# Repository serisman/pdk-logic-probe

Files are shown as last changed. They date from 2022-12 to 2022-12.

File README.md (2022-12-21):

# pdk-logic-probe
A simple logic probe, based on the ultra-inexpensive (~$0.03) Padauk microcontrollers.
- LED is Green when Probe pin is LOW.
- LED is Red when Probe pin is HIGH.
- LED is Blue when Probe pin is Floating.

### Links
- [Firmware](firmware/)
- [PCB](pcb/)

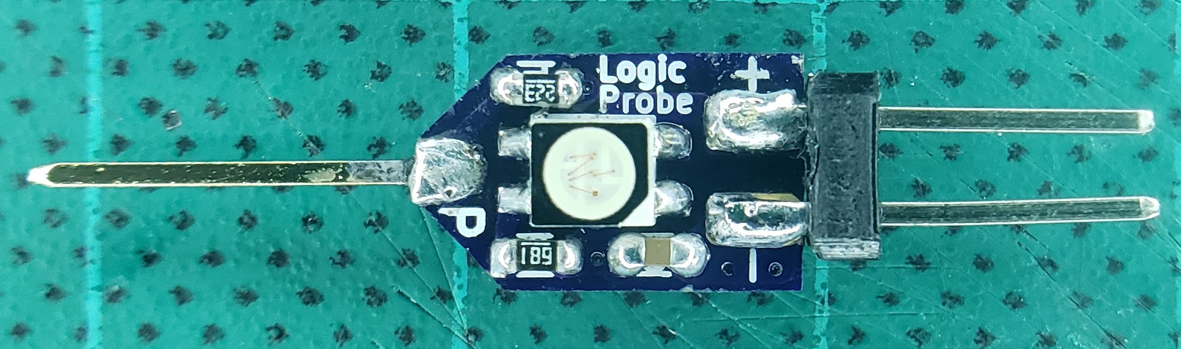
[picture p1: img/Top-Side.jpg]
Top Side

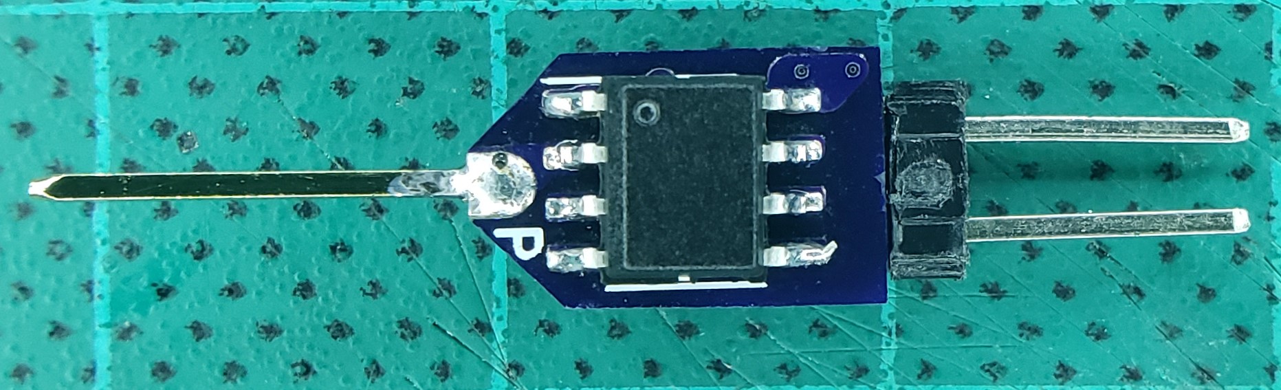
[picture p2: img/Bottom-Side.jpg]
Bottom Side


### Schematic
(for 8-pin PFS154, PFS173, PMS150C/PMS15A, PMS152, PMS154C, PMS171B)
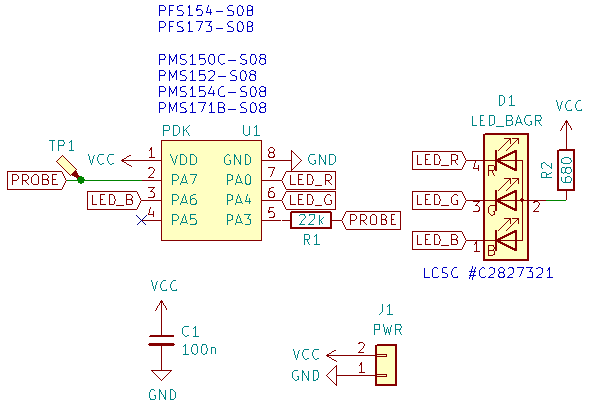
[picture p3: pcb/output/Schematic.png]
Schematic


### Usage
Connect (-) to GND and (+) to VCC
- LED is Green when Probe pin is LOW.
- LED is Red when Probe pin is HIGH.
- LED is Blue when Probe pin is Floating.

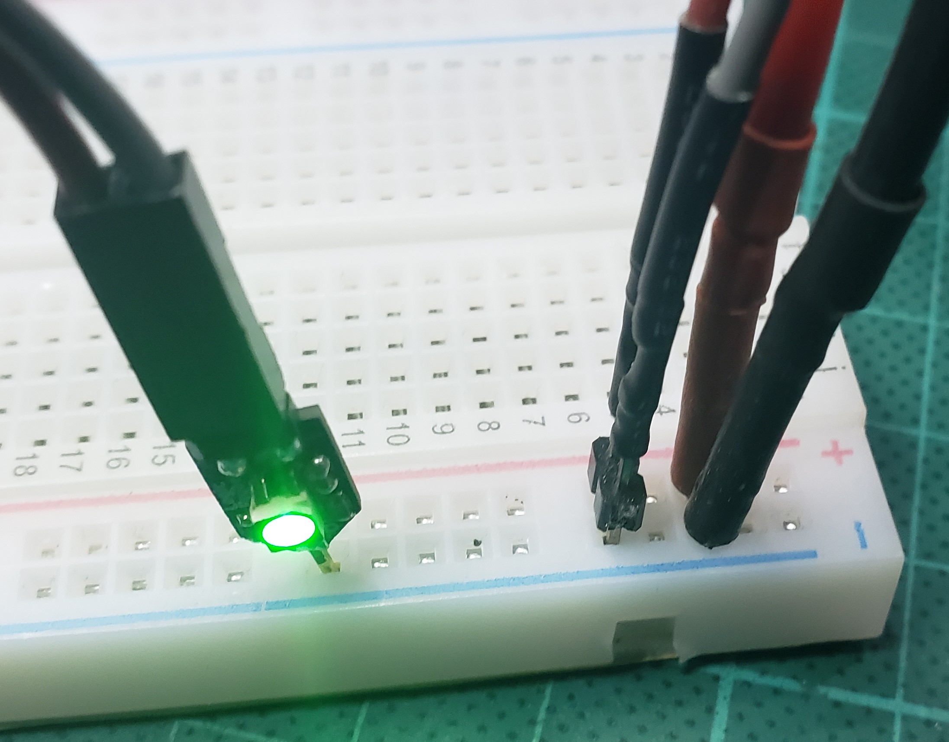
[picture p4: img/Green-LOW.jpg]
Green - LOW

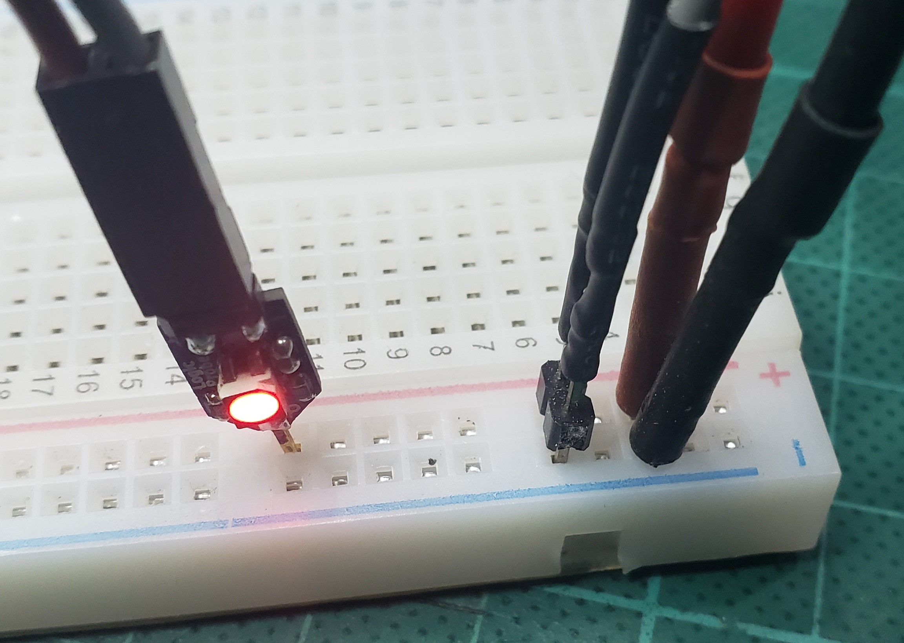
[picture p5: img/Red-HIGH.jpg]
Red - HIGH

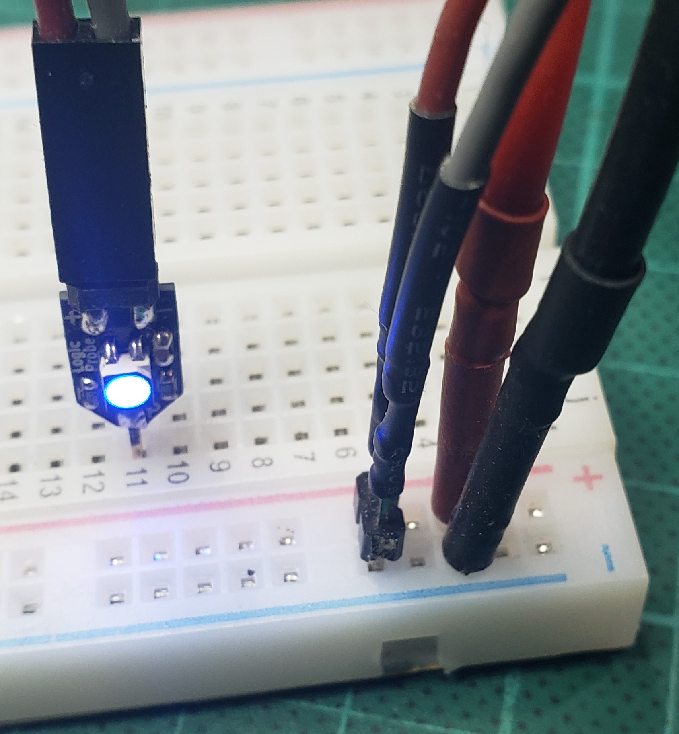
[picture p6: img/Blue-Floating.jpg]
Blue - Floating


### Compatibility
This project is currently intended to be run (without modifications) on the PFS154, PFS173, PMS150C/PMS15A, PMS152, PMS154C, and PMS171B Padauk microcontrollers,
but it should be able to be modified to run on just about every currently known Padauk microcontroller that is supported by SDCC and the Easy PDK Programmer.

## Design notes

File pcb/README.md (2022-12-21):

# pcb ([pdk-logic-probe](https://github.com/serisman/pdk-logic-probe/))

### Schematic
(for 8-pin PFS154, PFS173, PMS150C, PMS15A, PMS152, PMS154C, PMS171B)
Schematic

### PCB

This PCB design was created with KiCad, and has been [shared on OSHPARK](https://oshpark.com/shared_projects/ogOTS65P).
There are also gerber files available in the [output/gerber/](output/gerber/) directory, or [gerber.zip](output/gerber.zip).

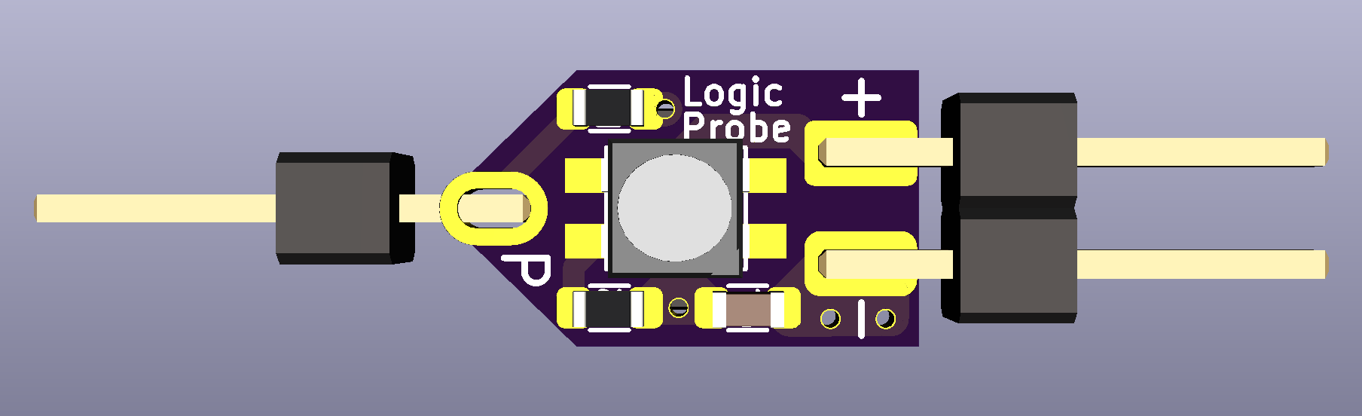
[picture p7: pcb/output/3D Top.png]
3D Top

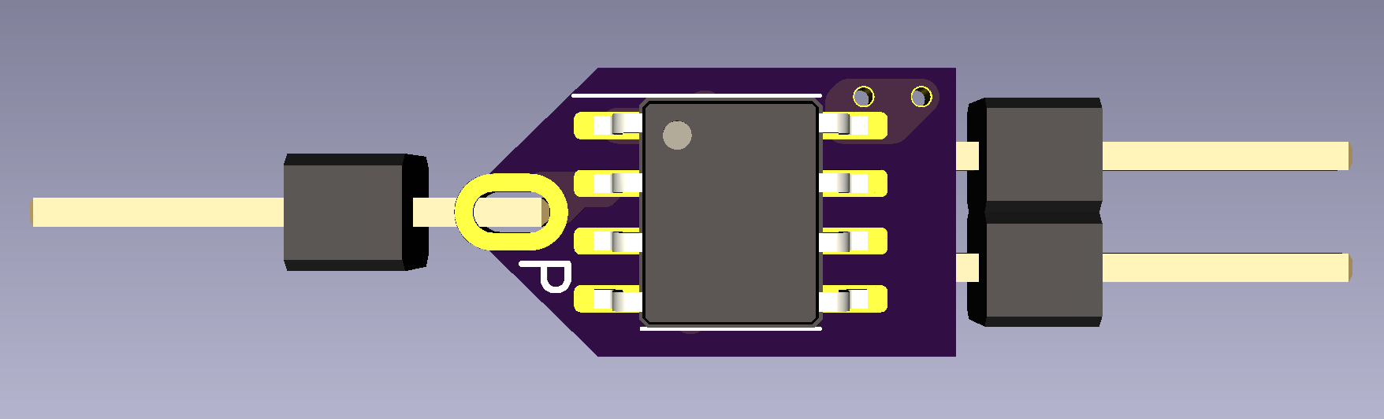
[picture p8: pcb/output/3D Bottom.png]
3D Bottom


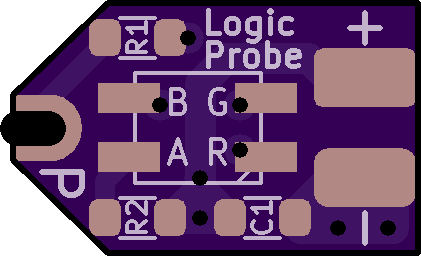
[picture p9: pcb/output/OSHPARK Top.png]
PCB Top

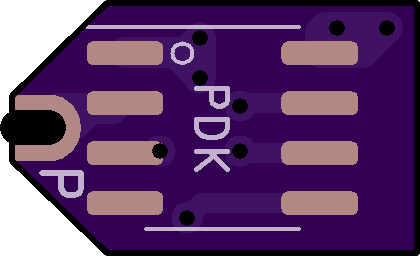
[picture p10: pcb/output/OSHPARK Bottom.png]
PCB Bottom


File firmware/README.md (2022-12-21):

# firmware ([pdk-logic-probe](https://github.com/serisman/pdk-logic-probe/))

### Toolchain:
- The open-source [Small Device C Compiler (SDCC)](http://sdcc.sourceforge.net/)
  - Requires version 3.9.0 or newer - version 4.0.0+ preferred
- The open-source [Easy PDK Programmer](https://github.com/free-pdk/easy-pdk-programmer-software)
  - Requires version 1.3 or newer
- The open-source [pdk-includes](https://github.com/free-pdk/pdk-includes) repository
  - Integrated via local copy into the pdk/ directory
- The open-source [easy-pdk-includes](https://github.com/free-pdk/easy-pdk-includes) repository
  - Integrated via local copy into the easy-pdk/ directory
- Also requires 'make' and other common build tools

### Build Commands:
```
make clean
make build
make size (also calls build)
make program (also calls size which calls build)
```
> Note: These commands can be chained as well.  i.e. `make clean program`

### Customization:
Edit the variables at the top of the Makefile to:
- **DEVICE**: Use a different Padauk MCU (defaults to PFS154)
- **TARGET_VDD_MV**: Use a different voltage while calibrating the internal oscillator (IHRC) (defaults to 3000mV)

> Note: Both of these variables can be changed on the commandline as well.  i.e. `make DEVICE=PFS173 clean program` 

### Compatibility
This project is currently intended to be run (without modifications) on the PFS154, PFS173, PMS150C/PMS15A, PMS152, PMS154C, and PMS171B Padauk microcontrollers,
but it should be able to be modified to run on just about every currently known Padauk microcontroller that is supported by SDCC and the Easy PDK Programmer.
Some microcontrollers will require additional definitions in the [hal.h](hal.h) file,
and less common devices may require additional device specific include files (pdk/device/*.h) to be supplied.

### Build Stats
- Code Size: ~92-97 words (depending on the microcontroller)
- RAM usage: 0 bytes + stack

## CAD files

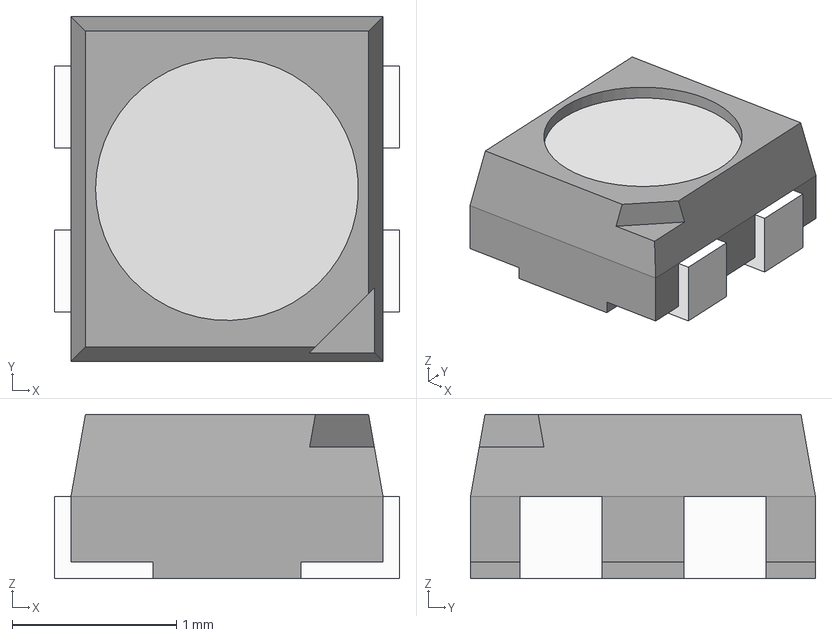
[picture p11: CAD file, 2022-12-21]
pcb/_3dshapes/RGB_LED_2121.step
2.10 x 2.10 x 1.00 mm

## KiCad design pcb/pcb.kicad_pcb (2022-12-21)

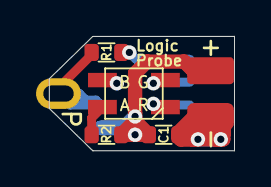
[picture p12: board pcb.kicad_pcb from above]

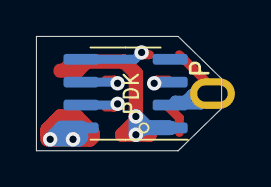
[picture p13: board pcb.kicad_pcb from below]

Board: 2 copper layers, 10.3 x 6.4 mm, 7 parts (2 on the bottom side), 8 nets.

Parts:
C1: 100n; C_0603
D1: LED_BAGR; LED_BAGR_3528
J1: PWR; PinHeader_1x02_P2.54mm_Horizontal
R1: 22k; R_0603
R2: 680; R_0603
TP1: Probe; PinHeader_1x01_P2.54mm_Vertical
U1: PDK; SOIC-8_3.9x4.9mm_P1.27mm

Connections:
GND: C1.2, J1.1, U1.8
LED_B: D1.1, U1.3
LED_G: D1.3, U1.6
LED_R: D1.4, U1.7
unnamed: D1.2, R2.2
unnamed: R1.1, U1.5
PROBE: R1.2, TP1.1, U1.2
VCC: C1.1, J1.2, R2.1, U1.1

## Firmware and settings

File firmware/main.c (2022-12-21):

/*
  pdk-logic-probe

  Copyright (C) 2022  serisman  <github@serisman.com>

  LED is Green when Probe pin is LOW.
  LED is Red when Probe pin is HIGH.
  LED is Blue when Probe pin is Floating.

  ----------------------------------------------------------------------
  CC BY 4.0
  Licensed under a Creative Commons Attribution 4.0 International license:
  http://creativecommons.org/licenses/by/4.0/
*/

#include <stdint.h>
#include <stdbool.h>
#include <pdk/device.h>
#include <easy-pdk/calibrate.h>

#if !defined(PFS154) && !defined(PFS173) && !defined(PMS150C) && !defined(PMS15A) && !defined(PMS152) && !defined(PMS154C) && !defined(PMS171B)
  #error "Device not currently supported!"
#endif

// Note: All pins are on Port A
#define PIN_R       0
#define PIN_G       4
#define PIN_B       6
#define PIN_OUT     3
#define PIN_PROBE   7

// Main program
void main() {

  // Disable wake-up on un-used pins to save power
#if defined(PBDIER)
  PBDIER = 0x00;
#endif
#if defined(PCDIER)
  PCDIER = 0x00;
#endif

  // Initialize Pins
  PAPH = 0x00;                              // Disable pull-up resistors
  PADIER = (uint8_t)(1<<PIN_PROBE);         // Enable digital input on PROBE
  PAC = (uint8_t)((1<<PIN_OUT)|(1<<PIN_R)|(1<<PIN_G)|(1<<PIN_B));  // Set OUT and RGB LED Pins as outputs
  PA = (1<<PIN_R)|(1<<PIN_G)|(1<<PIN_B);    // LEDs off by default

  // Main processing loop
  while (1) {

		PA |= (1<<PIN_OUT);                     // Turn OUT on (i.e. try to pull PROBE high)
		__nop();__nop();__nop();__nop();
		bool probeHigh = PA & (1<<PIN_PROBE);   // Test PROBE

		PA &= ~(1<<PIN_OUT);                    // Turn OUT off (i.e. try to pull PROBE low)
		__nop();__nop();__nop();__nop();
		bool probeLow = !(PA & (1<<PIN_PROBE)); // Test PROBE

		// Update LEDs
		if (probeHigh & probeLow) {
			PA = (1<<PIN_R)|(1<<PIN_G);           // Blue LED   (PROBE is Floating)
		} else if (probeLow) {
			PA = (1<<PIN_R)|(1<<PIN_B);           // Green LED  (PROBE is LOW)
		} else if (probeHigh) {
			PA = (1<<PIN_G)|(1<<PIN_B);           // Red LED    (PROBE is HIGH)
		}
  }
}

// Startup code - Setup/calibrate system clock
unsigned char _sdcc_external_startup(void) {

  // Set FUSE:
  // - 1.8v LVR (if available)
  // - Normal IO Drive (if available)
  // - Fast Bootup (if available)
  // - Security Off
#if defined(FUSE_LVR_1V8) && defined(FUSE_IO_DRV_NORMAL) && defined(FUSE_BOOTUP_FAST)
  PDK_SET_FUSE(FUSE_BOOTUP_FAST | FUSE_IO_DRV_NORMAL | FUSE_LVR_1V8 | FUSE_SECURITY_OFF);
#elif defined(FUSE_LVR_1V8)
  PDK_SET_FUSE(FUSE_LVR_1V8 | FUSE_SECURITY_OFF);
#elif defined(FUSE_IO_DRV_NORMAL) && defined(FUSE_BOOTUP_FAST)
  PDK_SET_FUSE(FUSE_BOOTUP_FAST | FUSE_IO_DRV_NORMAL | FUSE_SECURITY_OFF);
#elif defined(FUSE_BOOTUP_FAST)
  PDK_SET_FUSE(FUSE_BOOTUP_FAST | FUSE_SECURITY_OFF);
#else
  PDK_SET_FUSE(FUSE_SECURITY_OFF);
#endif

  // Set LVR:
  // - 1.8v (if available)
  // - otherwise 2.0v (if available)
#if defined(MISCLVR_1V8)
  MISCLVR = (uint8_t) MISCLVR_1V8;
#elif defined(MISCLVR_2V)
  MISCLVR = (uint8_t) MISCLVR_2V;
#endif

  // Initialize the system clock (CLKMD register) for 1MHz operation
  PDK_SET_SYSCLOCK(SYSCLOCK_IHRC_1MHZ);

  // Insert placeholder code to tell EasyPdkProg to calibrate the IHRC internal oscillator for 1MHz operation.
  EASY_PDK_CALIBRATE_IHRC(1000000, TARGET_VDD_MV);

  return 0;   // Return 0 to inform SDCC to continue with normal initialization.
}
